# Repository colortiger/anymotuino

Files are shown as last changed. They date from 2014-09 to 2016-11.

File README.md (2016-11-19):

Warning: this project has been discontinued
==========
Although the arduino DYI hardware still works, the pairing application (the AnyMote app) won't discover it as a valid AnyMote device. This is because none of the available BLE modules for Arduino allow for custom discovery data, which would make the overall connection & discovery of both AnyMote and Arduino DYI Anymotuinos significantly slower (10x slower)

anymotuino
==========

__anymotuino__ is an Arduino clone of our __AnyMote__ device (you can follow our KickStarter campaign [here](https://www.kickstarter.com/projects/1635386542/anymote-home-your-phone-the-ultimate-universal-rem)).

It behaves almost exactly as our __AnyMote__ device, although it lacks the optimisations we were able to integrate in our custom board and firmware.

__anymotuino__ follows the same protocol as __AnyMote__, so you can safely use it with our AnyMote [iOS (early beta)](https://colortiger.com/iosbeta) and [Android](https://play.google.com/store/apps/details?id=com.remotefairy&hl=en) applications.

What hardware do I need to build it? (Bill Of Materials)
========================================================

You can basically use any Arduino board along with a Bluetooth LE 4.0 compatible serial data module and InfraRed LED, but for the purposes of this example, we have chosen to use an Arduino Pro Mini (3.3V version) and an HM-10 BLE board, mainly to keep things nice and compact, while running on 2x AA batteries.

Here's the Bill Of Materials for this project:

1. [Arduino Pro Mini – 3.3V, 8MHz version](https://www.sparkfun.com/products/11114) (there's also a 5V, 16MHz version, but we only need 3V)
2. [HM-10 BLE 4.0 module](http://www.fasttech.com/product/1292002-ti-cc2540-cc2541-bluetooth-4-0-ble-2540-2541) (based on TI's powerful CC2540 BLE chip)
3. [Max Power IR LED Kit](https://www.sparkfun.com/products/10732) (Any IR LED will do, but this kit allows you to get the most power out of your Arduino for the best range)
4. [IR Receiver](http://www.adafruit.com/products/157?&main_page=product_info&cPath=35&products_id=157) (used for IR recording, if you need it)
5. [Mini Breadboard](https://www.sparkfun.com/products/12047)
6. Wires
7. [2xAA Battery Enclosure](https://www.sparkfun.com/products/9543) (I recommend buying one with a switch on it)

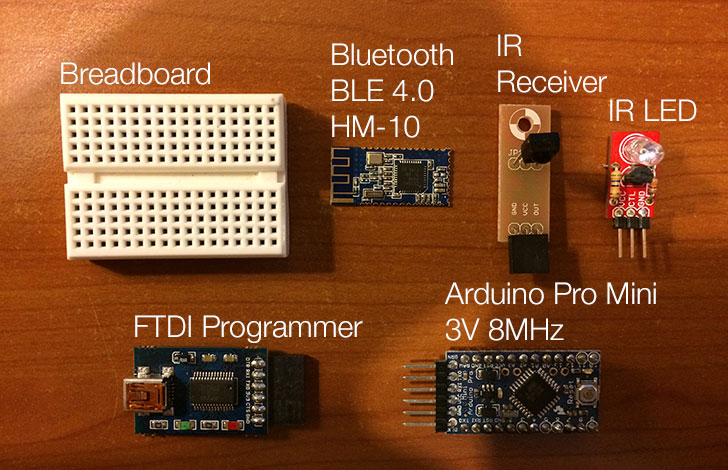
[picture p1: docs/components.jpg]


What software do I need to run it?
==================================

You need Arduino 1.0+ obviously, and you also need Ken Shirriff's [IRRemote library](https://github.com/shirriff/Arduino-IRremote).

How do I put it all together?
=============================

Here comes the fun part. Put your DIY glasses on and let's build this thing!
You can also find the Fritzing schematic [here](fritzing/Anymotuino.fzz).

1. Build the core of the device
-------------------------------

Stick the breadboard to the battery enclosure's back (all breadboards have a sticky double sided tape on their back). If you have a case with a switch on it, make sure you're not pasting the breadboard over it.

Then connect the Arduino Pro Mini on the breadboard as suggested in this photo. Make sure it goes over the length of the breadboard so we have both halves usable for connections.

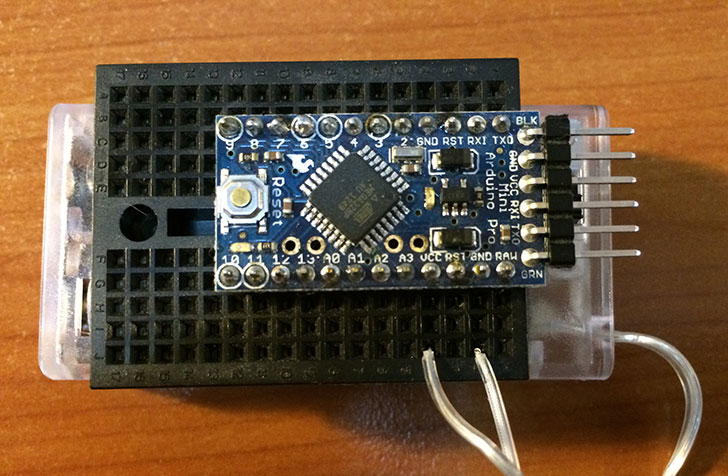
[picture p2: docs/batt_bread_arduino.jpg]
Breadboard over battery case and Arduino connected


2. Connect the Power IR breakout
--------------------------------

The breakout requires VCC and GND connections + the CTL pin. The CTL pin goes to pin 3 of the Arduino Pro Mini (which is a PWM pin, required for fast IR "ticks").

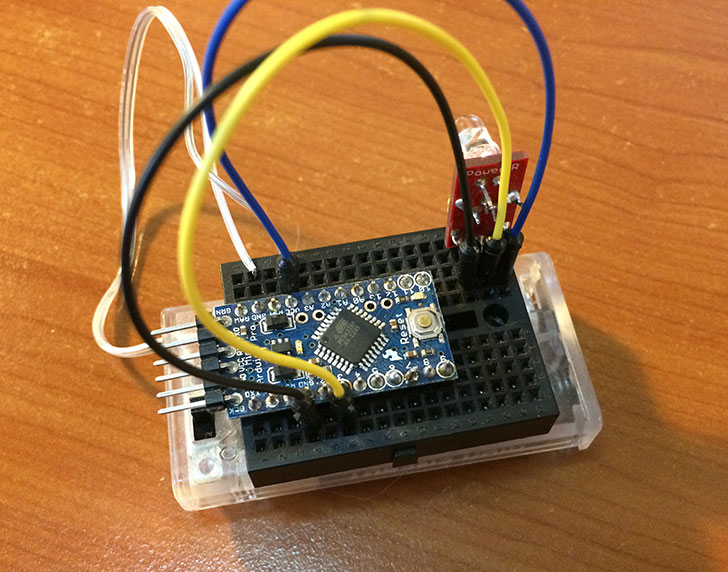
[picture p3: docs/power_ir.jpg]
Power IR Breakout connections


3. Connect the IR receiver breakout (optional)
----------------------------------------------

__anymotuino__ knows how to record IR codes as well. So if you bought an IR receiver breakout, you can use it by connecting the VCC and GND pins to their respective counterparts on our Breadboard, and the OUT pin to pin 6 on the Arduino board.

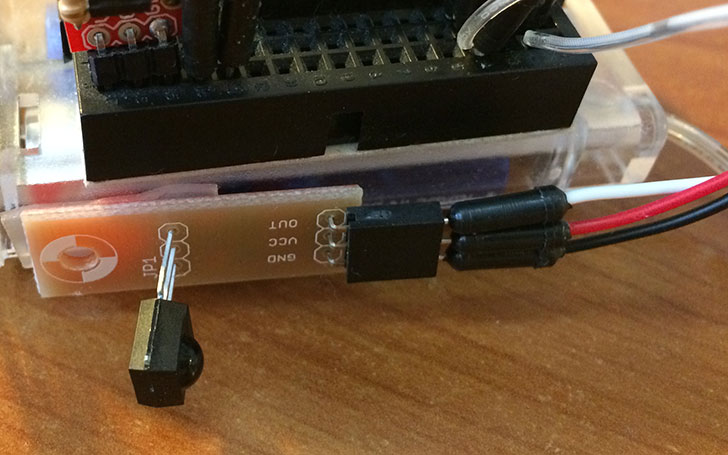
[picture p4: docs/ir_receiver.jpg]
IR Receiver Breakout connections


4. Solder the connections to the HM-10 module
---------------------------------------------

Normally you would need a [breakout board](https://oshpark.com/shared_projects/aWRbRvyh) for the HM-10 module, but for the purposes of our project, we'll solder the wires directly to the small board as in the photo. 

So, holding the module with the antenna on top, the first 2 pins on the bottom left side are GND and VCC, respectively; the 2 pins on the top left side are RX and TX, respectively. There's another pin you might want to solder since we're here, the status signal, useful for debugging. It's the 3rd pin on the bottom right side (orange wire in the photo).

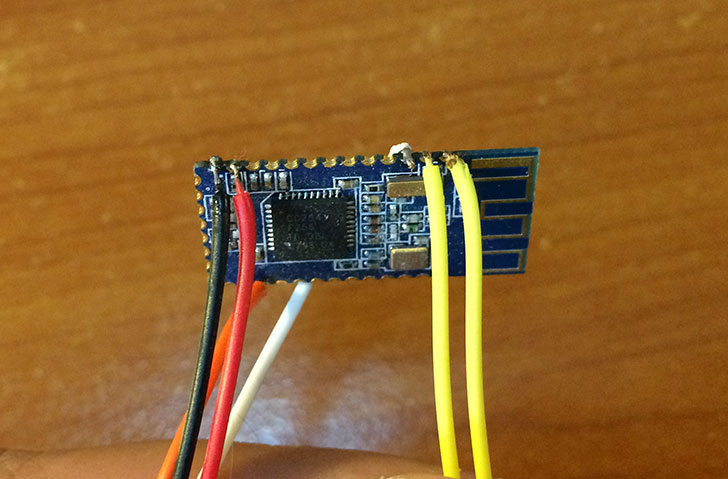
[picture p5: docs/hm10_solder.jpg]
HM-10 BLE module soldering


For more info, you can find the full schematics and documentation for the HM-10 [here](http://www.jnhuamao.cn/bluetooth40_en.zip).

5. Wire the HM-10 module to our Arduino Pro Mini
------------------------------------------------

Wiring it to the arduino is easy as pie once you soldered the wires. The VCC and GND wires go to their respective counterparts on our breakboard, while the RX and TX go to our 8 and 7 pins on the Arduino. In the Arduino sketch, the Serial connection is made to read from pin 8 and write to pin 7 (RX on the BLE goes to TX on the arduino and TX of the BLE to RX of the arduino).

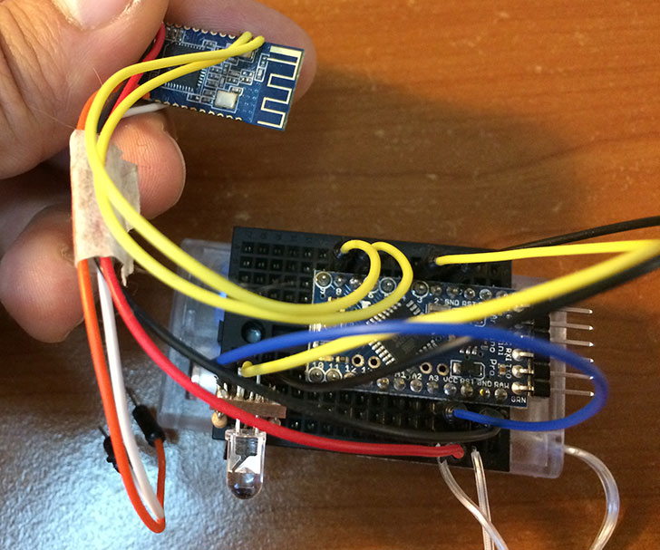
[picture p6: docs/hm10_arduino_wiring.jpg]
HM-10 wiring


Optionally, connect a LED to the status output of the HM-10 to debug connectivity. Blinking means not connected to a BLE device, solid means connected. The orange wire goes to the input end of the LED, while the GND goes to the arduino's GND.

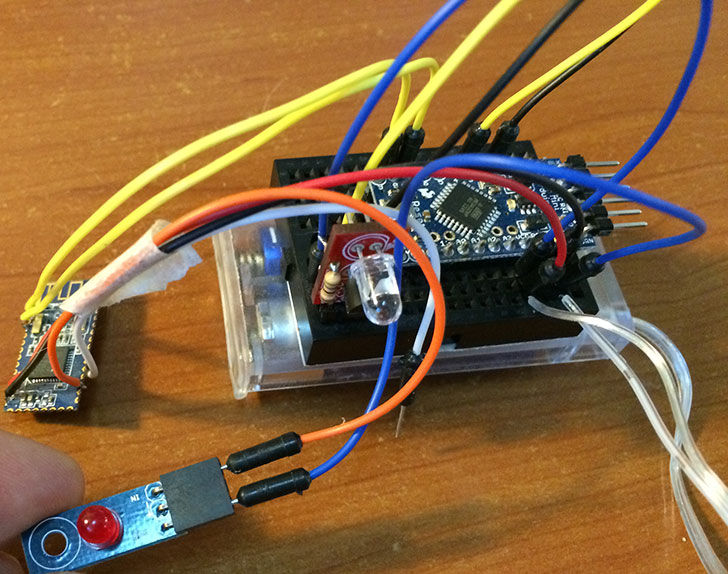
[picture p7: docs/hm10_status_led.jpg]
HM-10 optional status debug LED


6. That's it for the hardware
-----------------------------

I also applied 2 small pieces of double sided tape to hold the BLE module and the IR recorder together with our rudimentary-but-nonetheless-cool __anymotuino__ box:

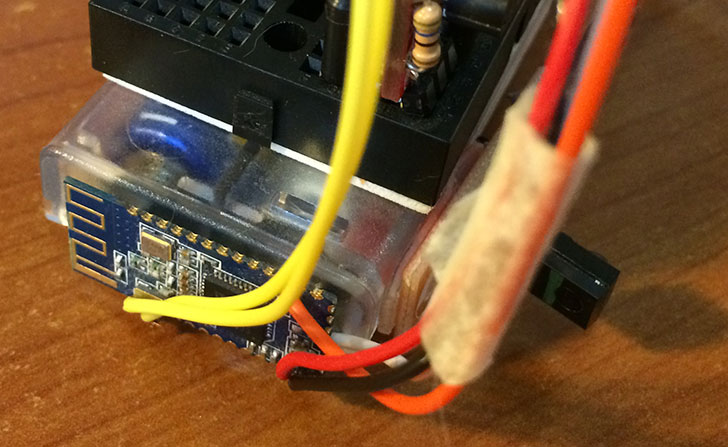
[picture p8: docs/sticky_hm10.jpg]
Sticky breakout boards


Final look:

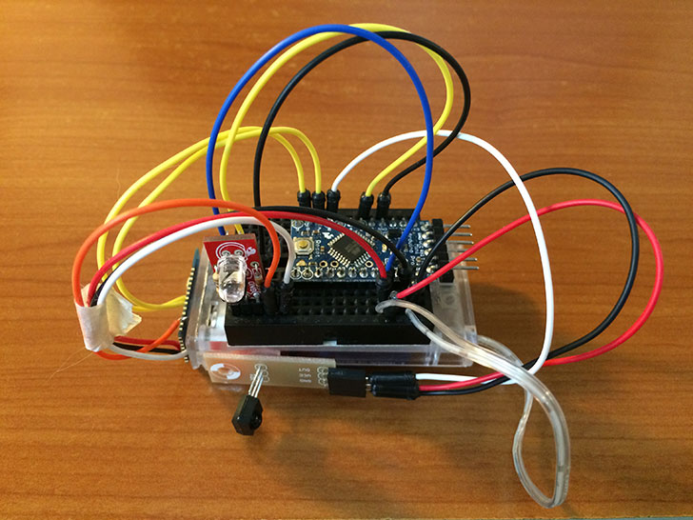
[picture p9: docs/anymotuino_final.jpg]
Final product


Don't forget, you can also find the Fritzing schematic [here](fritzing/Anymotuino.fzz).

Installing the Arduino Sketch and usage
=======================================

Sketch Installation And Configuration
-------------------------------------

You first need to install the [IRRemote](https://github.com/shirriff/Arduino-IRremote) library in your Arduino SDK's libraries folder. 

__Important:__ _You may get this error on compile on the latest Arduino IDE: `error: 'TKD2' was not declared in this scope`. The IRremote library is included in the RobotIRremote library shipped with the latest versions of the Arduino IDE which causes a conflict (the included version of IRremote is pretty old). Until the Arduino IDE devs fix this issue, you can get back to a successful build by deleting the RobotIRremote libary from the Arduino libraries folder, then close and reopen the Arduino IDE and rebuild._

__Important:__ _If you want to use the IR Recording feature, you have to make a small adjustment in the `IRRemote.h` file of the IRRemote library before opening the Arduino IDE:_

Replace this line:

```
#define USECPERTICK 50
```

With this snippet:
```
#ifndef USECPERTICK
#define USECPERTICK 50
#endif
```

This allows us to easily change the microsecond per signal tick as we need in our sketch. If you don't need this functionality, you can leave it as is.

Then fire up the Arduino IDE and load the [sketch](anymotuino/anymotuino.ino).

Connect the FTDI programmer to the Arduino Pro Mini board, then connect the FTDI programmer to a USB board on your computer.
Make sure you select the appropriate board type and serial port (Arduino Pro Mini 3.3V 8MHz ATmega328 and the appropriate Serial Port). Then choose `File > Upload` (or hit Command+U on OS X).

Once it's complete, you're able to use the __anymotuino__ with the SmartRemote/AnyMote iOS or Android application as an external IR blaster.

Enjoy!

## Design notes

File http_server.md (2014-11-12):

Creating a HTTP server compatible with Smart IR Remote
======================================================

To create an HTTP server with basic capabilities that can accept HTTP commands and forward them through InfraRed, you will have to implement 3 methods: *status*, *send* and *record*. This server can run on anything (Arduino, Raspberry Pi, a PC, etc ...), as long as it implements the methods below. It must run on port *9009*.

Getting the connected ir blasters (currently called "anymotes")
-----------------
####Request format:
http://[ip]:9009/api/status/
####Response format:
{"response":"success","anymotes":[{"address":"84:DD:20:E6:A5:03","name":"AnyMote Home"},{"address":"84:DD:20:E6:A5:43","name":"Remote41Q"}]}

Sending a code through. 
-----------------
Codes are formatted in as a simple decimals array, with the first one being the command frequency (usually 38000 +/- 10%), and then pairs of pulses with the on/off timings of the command. Assuming a frequency of 38000Hz, if you recorded a command using another arduino and you have the code in microseconds format (almost everybody does), you'll have to divide each number by 26 to get the pulses format we use.

####Request Format:
http://[ip]:9009/api/send?address=84:DD:20:E6:A5:43&code=38028,172,172,22,64,22,64,22,64,22,21,22,21,22,21,22,21,22,21,22,64,22,64,22,64,22,21,22,21,22,21,22,21,22,21,22,64,22,64,22,64,22,21,22,21,22,21,22,21,22,21,22,21,22,21,22,21,22,64,22,64,22,64,22,64,22,64,22,1820,
####Response OK:
{"message":"command sent","status":"success"}
####Response FAIL:
{"message":"there is no connected IR Blaster with that address","status":"error"}

Record a new command
-----------------
####Request Format:
http://[ip]:9009/api/record?address=84:DD:20:E6:A5:43
####Response OK:
{"status":"success","code":"39000,174,176,20,66,20,66,20,66,20,23,20,23,20,23,20,23,20,23,20,66,20,66,20,66,20,23,20,23,20,23,20,23,20,23,20,66,20,66,20,23,20,66,20,23,20,23,20,23,20,23,20,23,20,23,20,66,20,23,20,66,20,66,20,66,20,66,20,1285,"}
####Response FAIL ir blaster not connected:
{"message":"there is no connected IR Blaster with that address","status":"error"}
####Response FAIL recording failed / timed out after 60 seconds:
{"message":"recording failed","status":"error"}

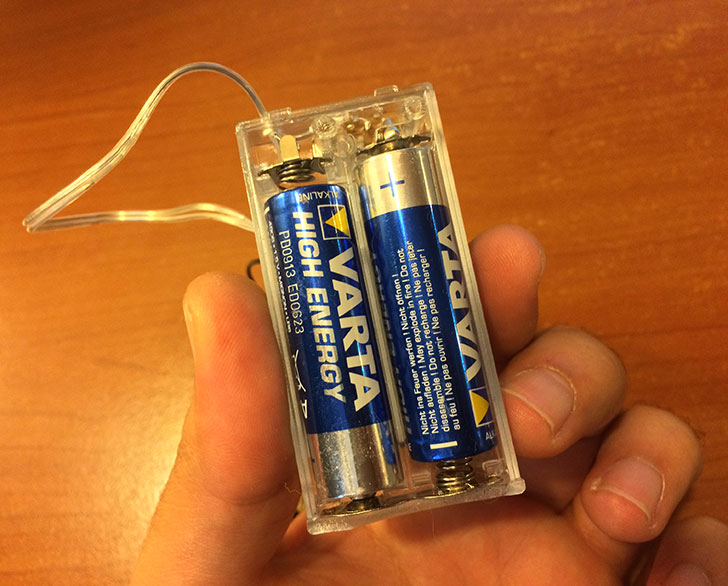
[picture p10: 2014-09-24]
docs/batt.jpg

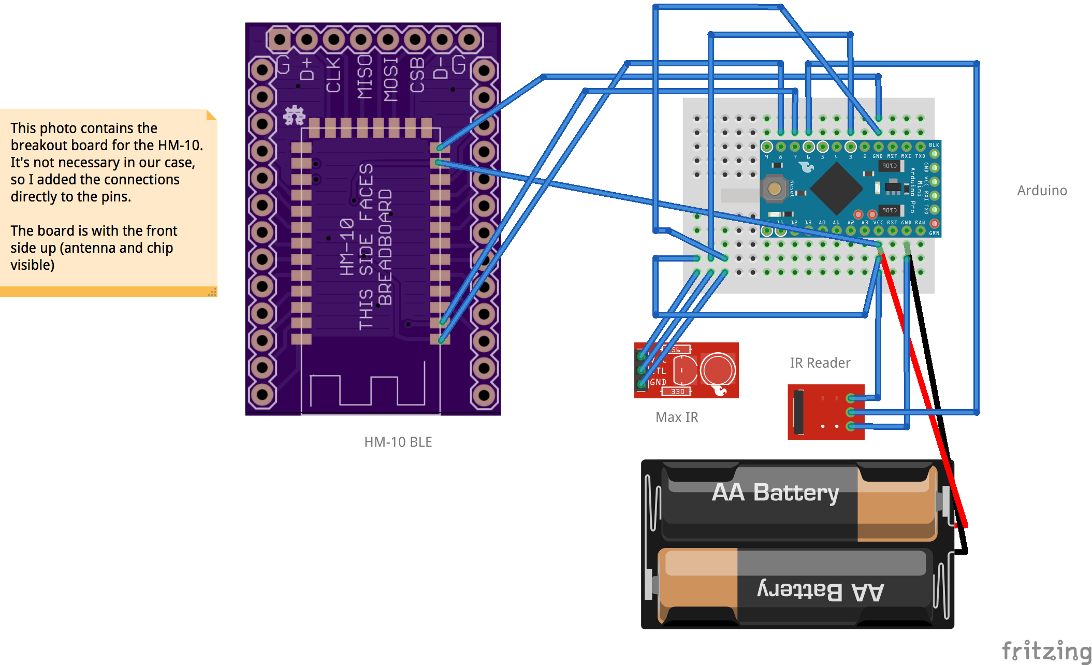
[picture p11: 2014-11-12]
fritzing/Anymotuino.png

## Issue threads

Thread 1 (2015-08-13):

IR Receiver not working

pholcroft, 2015-08-13:
No matter what I do I can't seem to get the IR Receiver to work. Everything else seems to work fine. can you recommend a way to debug this?

stumpja, 2016-01-05:
Pholcroft,

I'm happy to hear you have basically gotten your anymotuino to work. I have recently built one, but I an unable to connect to the iOS anymote app. I assume you are using iOS, or do you have an android phone that doesn't have an ir blaster? An information would be great. Thanks in advance for your time.

Josh

pholcroft, 2016-01-05:
Hi Josh,

I have an android phone (One Plus One) which doesn't have an IR blaster and I am using the Anymote App. It was a while ago now, but I can't remember have any problems getting it to work, did you add the test LED? I did email the developers of the Anymote app about some issues with the app and bluetooth, they responded with an updated version which fixed my issues. That is another route you could try.

stumpja, 2016-01-05:
Pholcroft,

I really appreciate the reply. I sent an email to them yesterday, but haven't heard back yet. I will say, I emailed them in the past and they were pretty responsive. Maybe I can borrow an android phone and rule out the hardware. Whats interesting, is that it just won't recognize the device at all, alluding to it not seeing the HM-10. I can connect to the HM-10 through another app (I.E. LIGHTBLUE). This leads me to thinking if I need to configure the HM-10 in some way for it to work properly with the app. Did you have to change the name of the HM-10 for the app to recognize it?

Anyways, thanks again for the quick response. So were you able to get the IR reciever to work properly with the app update?

Thanks,

Josh

pholcroft, 2016-01-05:
The hm-10 is really weird. I can't see it in my Bluetooth connection settings, but anymote connects to it somehow? I bought two of them and tried to update the second one with the latest firmware, but I couldn't get the serial connection to work to talk to it. The one I used in the device I used straight out of the packet. I didn't put too much effort into updating the second one though as I had it working with the first one. I think maybe I bought a hm-10 clone.

The issue with the app wasn't a major one. It was just when you sent the first command when the Bluetooth wasn't connected it wouldn't wait for the connection to finish before sending the command, but that was only an issue the first time I used it. It didn't stop me using it.

Really we need a version of this which uses the esp8266 instead of hm-10 Bluetooth, but I don't have the time to learn this at the moment to do it myself.

stumpja, 2016-01-05:
I'm starting to get the feeling it just isn't supported in the iOS version of the app. I have a couple other HM-10's I can try, but I don't have a good feeling about it. The iOS version of the app is free, presumably due to the fact that no iPhones have IR blasters, so they are likely forcing you to buy their anymote in order to use the app. I may end up buying the anymote, I just wanted to at least test the app and usability with the anymotuino first before I made the plunge.

Being able to use the ESP instead of the HM-10 would be great. I'm definitely more comfortable with wifi than bluetooth. The code for the arduino would be fairly straight forward, however the code for the android/ios app isn't available, so it would be impossible to implement without writing your own standalone application.

Again, thanks for all your help!

Josh

pholcroft, 2016-01-05:
The Anymote supports Global Cache iTach WiFi to IR devices. The spec is here:
http://www.globalcache.com/products/itach/wf2irspecs/
(the help in Anymote it says it works with iPhone's).
These devices aren't cheap.

The information is available, it just needs to be programmed using an arduino, or it's possible the esp8266 might even be able to handle it itself.

stumpja, 2016-01-06:
Very interesting. This would be a great project to work on. Provided I get some time I may dig deeper into this.

I did want to say. Color Tiger did get back with me this morning. The following response was given:

> *when you launch the iOS app and get to the "searching for your AnyMotes stage", after 8 seconds*
> *a message will appear. Right at the bottom of the screen, there will be an "I already have an*
> *AnyMote Home" text: long-press that, and you're into the "Anymotuino discovery mode".*

This has fixed my connection issue. I will begin testing the other features out. Thanks for all your feedback. it has been much appreciated. If I ever get around to working with the ESP8266 and Anymote I will post my results here.

Thanks again,

Josh

pholcroft, 2016-01-06:
Glad to hear you got it working and that Anymore were helpful.

The problem with Bluetooth is that it takes time to connect the first time you use it. This happens frequently when you walk out of Bluetooth range. Although the individual commands wait for connection, the macro's don't. Everytime I use the app I have to press OK, wait for that to show up on the screen, then press my macro button. WiFi would be a much better solution as connection shouldn't be an issue.

Please let me know if the recording feature works for you.

davcenmt2, 2016-11-06:
@pholcroft @stumpja do either of you still use your anymotuino. I'm having trouble getting anymote app to recognize the hm-10. I have a feeling its may not be compatible with newest version of anymote app as I was able to get really old version to recognize it but nothing worked.

I've emailed ColorTiger to see what they have to say, but wanted to see if you guys every had any trouble as the app updated?

stumpja, 2016-11-06:
@davcenmt2
I was able to connect with an older version and get commands to work properly, however, I had to shut down the app every time and reconnect when I wanted to use it again. Due to this, I stopped using it.

I still have the hardware laying around in pieces at the moment. I would love to get it going, just figured it might be easier to use another app to get it to do what I really want. I really like Bluetuino, it isn't perfect, but it works and is customizable. The user interface isn't the greatest, but it should work, will require some more in depth programming and app design though. Check it out. I haven't had time yet to really get this going, just verifies basic functionality. One other thought, just recently backed a project of Indiegogo called riimo. This could solve my problems, assuming they deliver. Check that out as well. They have partnered with arrow, a highly respected distributer, so that is a good sign.

If you do hear back from color tiger, please post the response here. I like the app, and if it would work, I'd love to use it. Thanks!

davcenmt2, 2016-11-06:
@stumpja
Thanks for the fast reply. I'll definitely let you know what I hear from them. I'd love if I could get it working! Coming from an S5 with IR blaster built in, that's one thing I miss with my new phone.

I'll have to check out the Bluetuino alternative. thanks for the suggestions.

davcenmt2, 2016-11-19:
@stumpja
looks like anymotuino is no more. Finally got a reply from Colortiger -

"am sorry for this, we'll have to remove anymotuino from Git as it interferes with AnyMote. (and we had to remove it from our app too in the last updates)
It makes the discovery of AnyMote devices very slow as we have to look out for anymotuino devices."

Closed 2022-03-16.

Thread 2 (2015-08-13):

Max Power IR LED Kit

pholcroft, 2015-08-13:
This kit recommended is designed to work with 5v. As we are using 3.3V I'd recommend changing the IR limiting resistor to something lower to allow maximum power to the led.

http://cdn.sparkfun.com/datasheets/Kits/PowerIR-v11.pdf

Closed 2022-03-16.

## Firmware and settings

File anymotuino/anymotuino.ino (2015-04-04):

/*
 File: anymotuino.ino
 Abstract: Open Source code of the Arduino Anymote code

 Version: 1.0

 Disclaimer: IMPORTANT:  This Color Tiger software is supplied to you by Color Tiger
 Inc. ("Color Tiger") in consideration of your agreement to the following
 terms, and your use, installation, modification or redistribution of
 this Color Tiger software constitutes acceptance of these terms.  If you do
 not agree with these terms, please do not use, install, modify or
 redistribute this Color Tiger software.

 In consideration of your agreement to abide by the following terms, and
 subject to these terms, Color Tiger grants you a personal, non-exclusive
 license, under Color Tiger's copyrights in this original Color Tiger software (the
 "Color Tiger Software"), to use, reproduce, modify and redistribute the Color Tiger
 Software, with or without modifications, in source and/or binary forms;
 provided that if you redistribute the Color Tiger Software in its entirety and
 without modifications, you must retain this notice and the following
 text and disclaimers in all such redistributions of the Color Tiger Software.
 Neither the name, trademarks, service marks or logos of Color Tiger Inc. may
 be used to endorse or promote products derived from the Color Tiger Software
 without specific prior written permission from Color Tiger.  Except as
 expressly stated in this notice, no other rights or licenses, express or
 implied, are granted by Color Tiger herein, including but not limited to any
 patent rights that may be infringed by your derivative works or by other
 works in which the Color Tiger Software may be incorporated.

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
 IN NO EVENT SHALL COLOR TIGER BE LIABLE FOR ANY SPECIAL, INDIRECT, INCIDENTAL
 OR CONSEQUENTIAL DAMAGES (INCLUDING, BUT NOT LIMITED TO, PROCUREMENT OF
 SUBSTITUTE GOODS OR SERVICES; LOSS OF USE, DATA, OR PROFITS; OR BUSINESS
 INTERRUPTION) ARISING IN ANY WAY OUT OF THE USE, REPRODUCTION,
 MODIFICATION AND/OR DISTRIBUTION OF THE COLOR TIGER SOFTWARE, HOWEVER CAUSED
 AND WHETHER UNDER THEORY OF CONTRACT, TORT (INCLUDING NEGLIGENCE),
 STRICT LIABILITY OR OTHERWISE, EVEN IF COLOR TIGER HAS BEEN ADVISED OF THE
 POSSIBILITY OF SUCH DAMAGE.
 */

#include <SPI.h>
#include <Boards.h>

#define USECPERTICK 26 // we're defining the microseconds per tick to work with 38KHz codes (the most used frequency) - a tick of 26us = 38KHz

// IMPORTANT! You may get this error on compile on the latest Arduino IDE: error: 'TKD2' was not declared in this scope
// The IRremote library is included in the RobotIRremote library shipped with the latest versions of the Arduino IDE
// which causes a conflict (the included version of IRremote is pretty old). Until the Arduino IDE devs fix this
// issue, you can get back to a successful build by deleting the RobotIRremote libary from the Arduino libraries folder,
// then close and reopen the Arduino IDE and rebuild.
#include <IRremote.h>
#include <IRremoteInt.h>
#include <SoftwareSerial.h>

//  --- config ---

// uncomment this to get debug info over the serial monitor
//#define DEBUG_LOGS

#define CODE_BUF_SIZE 200 // the IR code array buffer size
#define FREQ_MULTIPLIER 250 // to save bandwidth, the freq is divided by this value when transmitted OTA
int RECV_PIN = 6;
int BLE_RX_PIN = 8;
int BLE_TX_PIN = 7;

// --- commands ---
#define COMMAND_SEND 1 // the send command
#define COMMAND_READ 4 // the record from IR command

// --- constants ---
#define MODE_WAITING 0  // waiting for next command, idle
#define MODE_SEND 1     // reading a code from BLE to send over IR
#define MODE_TRANSMIT 2 // transmitting over IR
#define MODE_RECORD 3   // recording a code from IR to send over BLE
#define MODE_RETURN 4   // sending a recorded code back to BLE

// IR objects
IRsend irsend;
IRrecv irrecv(RECV_PIN);
SoftwareSerial bt(BLE_RX_PIN, BLE_TX_PIN);

decode_results results; // the results from the code decoding

int mode; // the current mode

struct {
  unsigned int code[CODE_BUF_SIZE]; // the code ticks buffer
  int len; // length of the code
  unsigned int freq; // in kHz
  bool complete; // true if the code read has completed
  int repeat; // the repeat count of the IR signal
  unsigned char firstByte; // first byte, in case it's a multibyte number
} pendingCode;


// =================
// ==== helpers ====
// =================

void resetPendingCode() {
  pendingCode.len = 0;
  pendingCode.freq = 0;
  pendingCode.complete = false;
  pendingCode.repeat = -1;
  pendingCode.firstByte = 0;
}

void goToWaitingMode() {
  mode = MODE_WAITING;
  resetPendingCode();

  cli();
  TIMER_CONFIG_NORMAL();

  //Timer2 Overflow Interrupt Enable
  TIMER_DISABLE_INTR;

  TIMER_RESET;
  sei();  // enable interrupts

  results.rawlen = 0;
}

// sends a code to the device via the IR output
void sendCode(unsigned int code[], int count, int repeat) {
  if (repeat == 0) {
    repeat = 1;
  }

  Serial.println(repeat);

  for (int r = 0; r < repeat; r++) {

    digitalWrite(13, HIGH);

    irsend.sendRaw(code, count, pendingCode.freq);

#ifdef DEBUG_LOGS
    Serial.print("Transmitted ");
    Serial.print(count);
    Serial.print(" raw codes");
    Serial.println();
#endif

    //    delay(10); // small delay between codes
    digitalWrite(13, LOW);
  }
}

void writeCodeToBLE() {
  bt.print((char)(38000 / FREQ_MULTIPLIER)); // send the frequency (divided by 250 as the standard imposes)
  Serial.print((char)(38000 / FREQ_MULTIPLIER));
  Serial.print(",");
  for (int i = 0; i < results.rawlen; i++) {
    int val = results.rawbuf[i];
    if (val > 0x7f) {
      int b1 = (val >> 7) & 0x7f; // skip the last bit
      int b2 = (val & 0x7f);
      char c1 = b1;
      char c2 = b2 & 0x7f;
      c1 = ~c1 + 1;
      bt.print((char)c1);
      bt.print((char)c2);
      Serial.print((int)c1);
      Serial.print(",");
      Serial.print((int)c2);
      Serial.print(",");
    } else {
      bt.print((char)val);
      Serial.print((int)val);
      Serial.print(",");
    }
  }
  bt.print((char)0);
  Serial.print((int)0);
#ifdef DEBUG_LOGS
  Serial.println("sent code to requester");
#endif
}


// =================
// ==== set up =====
// =================

void setup() {
  // Enable serial debug
  Serial.begin(57600);

  bt.begin(9600);

  resetPendingCode();

  mode = MODE_WAITING;

#ifdef DEBUG_LOGS
  Serial.println("Started up.");
#endif
}


// =================
// === main loop ===
// =================

void loop() {
  if (bt.overflow() && mode == MODE_SEND) {
    while (bt.read() >= 0) {
      ; // consume the stream
    }
#ifdef DEBUG_LOGS
    Serial.println("\nbuffer overflow; resetting...");
#endif
    mode = MODE_WAITING;
    resetPendingCode();
  }

  //  digitalWrite(13, LOW);

  if (MODE_SEND == mode) {
    // read more bytes from the stream
    if (bt.available() > 0) {
      int data = bt.read();

      if (pendingCode.freq == 0) {
        // frequency time
        pendingCode.freq = data * FREQ_MULTIPLIER / 1000; // transform it to kHz
#ifdef DEBUG_LOGS
        Serial.print("freq=");
        Serial.println(pendingCode.freq);
#endif
      } else if (data != 0) {
        // byte came in, sort it out
        if (!pendingCode.complete) {
          // continue
          if (data > 0x7f && 0 == pendingCode.firstByte) {
            // first part of a multi-byte int
            pendingCode.firstByte = 256 - data; // convert it back to positive
          } else {
            int usecpertick = 1000/pendingCode.freq;
            if (pendingCode.firstByte != 0) {
              unsigned int num = (unsigned int)pendingCode.firstByte << 7;
              num += data;
              pendingCode.code[pendingCode.len++] = num * usecpertick;
              pendingCode.firstByte = 0;
            } else {
              pendingCode.code[pendingCode.len++] = (unsigned int)data * usecpertick;
            }
          }
        } else {
          // even though it's not zero, it might still be the repeat count if the separator went through already
          pendingCode.repeat = data;
        }
      } else {
        if (!pendingCode.complete) {
          // 0 came in, acts as separator
          if (pendingCode.len % 2 != 0) {
            // add the last space if necessary
            pendingCode.code[pendingCode.len++] = 100;
          }
          pendingCode.complete = true;
        } else {
          // code already complete, 1 repeat
          pendingCode.repeat = 1;
        }
      }

      if (pendingCode.complete && pendingCode.repeat > 0) {
        // get out of this mode
        mode = MODE_TRANSMIT;
      }
    }

  } // send mode
  // handle the other functional cases
  else if (MODE_TRANSMIT == mode)  {
    // got a code waiting to be sent via ir, take care of it now
    sendCode(pendingCode.code, pendingCode.len, pendingCode.repeat);

    // reset the pending code
    goToWaitingMode();
  } else if (MODE_RECORD == mode) {

    if (irrecv.decode(&results)) {
      // get into code return mode to make sure nothing stands in our way
      mode = MODE_RETURN;

#ifdef DEBUG_LOGS
      Serial.print("Code recorded with length: ");
      Serial.println(results.rawlen);
#endif

      // pass it along and be done with it
      writeCodeToBLE();

      irrecv.resume(); // resume

      // return to idle
      goToWaitingMode();
    }

    if (bt.available()) {
#ifdef DEBUG_LOGS
      Serial.println("Command received while in record mode, cancelling...");
#endif

      goToWaitingMode();
      irrecv.resume(); // resume
    }

  } else if (MODE_WAITING == mode) {

    // waiting
    digitalWrite(13, HIGH);

    if (bt.available() > 0) {
      // a command came in, handle it
      unsigned int command = (unsigned int)bt.read();
#ifdef DEBUG_LOGS
      Serial.print("Received command type: ");
      Serial.println(command);
#endif

      if (COMMAND_SEND == command) {
        mode = MODE_SEND;
      } else if (COMMAND_READ == command) {
        mode = MODE_RECORD;
        irrecv.enableIRIn(); // Re-enable receiver
      }
    }

  }

}

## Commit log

2014-09-25 Updated Arduino Instructions
2014-10-28 Updated with Fritzing schematic; updated the iOS beta download link
    [Anymotuino.fzz]
2014-10-29 Fixed mutation of code array on repeat
    [anymotuino.ino]
2014-11-12 Fixes BLE RX,TX wiring
    [Anymotuino.fzz]
2015-03-30 fixed compile error for newer Arduino SDKs
    [anymotuino.ino]
2015-03-30 Updated Readme with important note about the IRremote library being included wrongfully in a default Arduino library
2015-04-04 Fixes wrong codes being sent via IR when built on new Arduino SDKs
    [anymotuino.ino]
